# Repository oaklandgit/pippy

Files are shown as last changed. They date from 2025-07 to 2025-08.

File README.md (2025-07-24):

pippy-logo

> [!IMPORTANT] 
> **Pippy is a work in progress, evolving in the open.** Expect bugs, half-built features, and changing plans. \
> [Follow the dev log here](devlog/)

Pippy is a compact, text-first Linux computer with a deliciously tactile 47-key mechanical keyboard. It connects to your iPad with a single USB cable, providing the Pippy with its power and display. Pippy returns the favor with a real shell, focused terminal tools, and a satisfying typing experience. It’s a seamless, symbiotic setup: minimalist, portable, and built for people who love computing at its most intentional.

> [!NOTE]
> The mascot is named "Shelby" or just "Shel" for short. Fun fact: there are _tortoises_ (land) and _turtles_ (water). Shelby is a _tortle_ (air).
> 
85CDC034-619D-4F67-B4E2-E74E878EFC01_1_102_o

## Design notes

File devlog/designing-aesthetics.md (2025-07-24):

CleanShot 2025-07-22 at 15 44 50

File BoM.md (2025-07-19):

# Bill of Materials (BoM)

This file documents all hardware, electronic, and software components used in the **Pippy** project. I'd call it a $150 project, depending on what materials you use for the enclosure.

## Hardware

| Item | Quantity | Purpose | Approx. $ |
| --- | --- | --- |---:|
| [Raspberry Pi Zero W](https://www.raspberrypi.com/products/) | 1 | Main computer | $15.00 |
| MicroSD Card (64GB A1, Class 10) | 1 | Storage and OS — fast, reliable boot performance | $12.00 |
| 4-Port USB Hub (e.g. [Adafruit 4115](https://www.adafruit.com/product/4115))  | 1 | Compact USB expansion hub | $7.00 |
| USB-A to Micro USB Cable (flexible) | 1 | Connects hub to Pi Zero | $9.00 |
| USB-A to USB-C Cable (flexible) | 1 | Connects hub to keyboard | $9.00 |
| 47-key Mechanical Keyboard (e.g. [MicroCenter](https://www.microcenter.com/product/661264/inland-47-keys-hot-swappable-rgb-wired-mechanical-keyboard)) | 1 | Tactile custom keyboard with backlighting | $40.00 |
| Custom Keycaps (e.g. [FKCaps.com](https://fkcaps.com/custom/)) | 47 | Low-profile, shine-through, MX-compatible caps | $60.00 |

iPad not included.

## Software

- iPad Terminal application (e.g. [Termius](https://termius.com/free-ssh-client-for-ipad) or [Le Terminal](https://apps.apple.com/us/app/la-terminal-ssh-client/id1629902861))
- Raspberry Pi OS (Legacy, 32-bit "Bullseye")
- Pippy (see [setup the guide](docs/setup-guide.md))

## Enclosure

- Basswood (for now!)

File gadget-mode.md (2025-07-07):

# Setting up a direct connection between a Pi Zero W and an iPad with "USB Gadget Mode"

July 2-5, 2025 

I've been working on building my dream console I'll refer to as "Pippy." In concept, it's compact, yet sports a delicious-to-type-on ortholinear "planck" style keyboard, and is driven by a Raspberry Pi Zero W under the hood. What it lacks in power it makes up for in portability, user experience, and a chill, retro aesthetic.

From the start, while the choice of keyboard was obvious to me, a suitable display and battery proved elusive. I simply couldn't find a screen with the brightness, power efficiency and form factor I wanted.

But it occured to me that I already have a device with a display and battery that I would want to carry around alongside Pippy anyway. My iPad.

My iPad Air not only has a nice, bright screen and long-lasting battery, its form factor is ideal for drawing and content consumption.

What my iPad sorely lacks, however, is the ability to do any modicum of coding (for my professional work as a user experience designer and software developer) and tinkering with the system itself (part and parcel for what it means to do computing IMHO). Despite all the processing power of its iPad lineup, Apple still refuses to endow it with the capabilities of an openly-accessible system like MacOS. Despite recently-announced updates that give iPadOS a more Mac-like windowing experience, it's not sufficient for coders and tinkerers like myself.

By pairing an iPad with a Raspberry Pi, I could leverage each's strengths: all the benefits of iPad things while providing power and a great display power for my Pi, so that *it* can handle the Linuxy things.

But figuring out precicely *how* sent me down a rabbit hole of false starts, dead ends. And while it was surprisingly tricky to figure out how to actually pull it off, once I learned it is actually quite elegant and easy.

So I'll share that with you. But first, let's look at…

### What Didn't Work

#### Over-the-Network Connectivity
Using SSH and VNC to interact with a Pi over the network is trival, and there are plenty of tutorials to show you the ropes. Basically, both the iPad and Pi join the same network, and the Pi is configured to open its SSH and/or VNC to be accessed by a guest device. It works fine, but has one fatal flaw for my use case: It's not a good choice for use on a *portable, and integrated* device because it relies on that shared network connection which 1) may not always be available and 2) must be configured on each device to join a new network and 3) firewalls and the like. Also, it seems like overkill to leverage a *remote-connection* technology by two devices that are literally attached to one another!

#### Serial UART Connectivity
Which brings me to the option of serial communications. Could I connect from the iPad's USB C to the Pi using good, old-fashioned TX and RX? Between a Mac and Pi yes. You need USB to Serial adapter (ie one with an FTDI chip) and some simple wiring to the Pi's GPIO pins. But when you swap in an iPad for the Mac, you're suddenly faced with the frustrating truth: being a closed system, the only devices and software I could find to make that connection are proprietary and expensive (and often recurring, subscription-based at that!) No thanks. Regardless, even if it were free, Serial has limitations of its own. It's a slow way to send data back and forth. Remember, these 2 devices are meant to act as one. Being *physically connected* yet still slower than Over-the-Network connectivity seemed like a step backwards.

### Enter "USB Gadget Mode!"
This solution not only works for my use case, it brings with it benefits that align perfectly that -- once you figure out *how* -- does not feel at all like a hack. It's both elegant and aligned with the task.

Basically, USB Gadget mode turns a USB connection into a direct ethernet connection between the devices. While ethernet is itself a "networking" technology, it is fast enough to be considered a bridge for local computing. When you keep in mind that a cluster of Raspberry Pis are often wired together via Ethernet as a single big brain, you realize this. And one incredibly convenient benefit is that this connection can share both data and power, which speaks to my original goal: using my iPad as a display AND power source for the Pi.

### Here's how to do it:

(I'm capturing this both for readers who might be interested in using this setup in their projects, but also for future me who -- despite having spent the better portion of a week focused on this -- will certainly forgot how once the dust has settled and I've gone on to the next shiny problem.)

#### STEP 1: Make the physical connection
Connect the Mac or iPad's USB C port to the Pi's Micro USB Data/Power port. IMPORTANT: Make sure to use the Data/Power USB port on the Pi and NOT the Power-only one. Also make sure your cable isn't garbage. **An additional Power source is not required!** The Pi will receive its power from the Gadget Mode connection.

#### STEP 2: Configure the Pi for Gadget Mode
Add the following to the `[all]` section of `/boot/config.txt`

```sh
dtoverlay=dwc2
```

Add `modules-load=dwc2,g_ether` after `rootwait` in `/boot/cmdline.txt`. **Make sure it's all on one line, and notice where there are and aren't spaces.** It doesn't matter if what you have is different as long as `modules-load=dwc2,g_ether` is inserted after `rootwait`.

```sh
console=serial0,115200 console=tty1 root=PARTUUID=71603c9d-02 rootfstype=ext4 fsck.repair=yes rootwait modules-load=dwc2,g_ether quiet splash plymouth.ignore-serial-consoles cfg80211.ieee80211_regdom=US
```

### STEP 3: Configure networking on the Pi 
**Here's the part that I haven't found well documented elsewhere.**

I had two problems at this point. 1) The Pi would not cooperate with dynamic IP addresses and 2) The Pi could only handle one type of connection at a time, which means it couldn't access the Internet while simultaneously connected to the iPad. Sort of a a dealbreaker.

The solution is to set up the Pi with a static IP address for the USB mode, and two interfaces: "usb0" for allowing the iPad to connect to it and "wlan0" for giving itself access to the Interwebs.

To do this, add this to the end of `/etc/dhcpcd.conf`

```sh
interface usb0
    static ip_address=192.168.2.2/24
    static routers=192.168.2.1
    static domain_name_servers=192.168.2.1 8.8.8.8
    metric 300

interface wlan0
    metric 100
```

#### STEP 3A: Connecting from a Mac
Even though a Mac-to-Pi connection was not my intended goal, I found it helpful to do first since there are fewer gotchas.

mac-interface
1. Find the "RNDIS/Ethernet Gadget" interface in `System Preferences → Network`
2. Manually configure IP to `192.168.2.1`, subnet mask to `255.255.255.0`

#### STEP 3B: Connecting from an iPad
1. Since the iPad only has a single USB C port, this is where a small USB hub becomes necessary: Keyboard and Pi Zero → Hub → iPad USB C.
2. You'll find the RNDIS/Ethernet gadget connection under `Settings → Ethernet`. There, they work the same as on a Mac. Set the Manual IP and Subnet Mask.
3. On the iPad, `Accessibility → Keyboards & Typing → Full Keyboard Access` should be turned OFF. With it on, many of the iPad's special keyboard shortcuts for operating the iPad interfere with the SSH Client (Blink app).

#### STEP 4: Give it a whirl!
You should be able to connect the same way you would over the network, using the machine's host name, as opposed to the IP address. Of course, use the username and hostname of your Pi.
```sh
ssh laz@pippy.local
```

### Changing WIFI networks
To recap, the whole point of this was to be able to connect an iPad to a Pi Zero with a single USB cable even without them both being on a shared network. That said, you likely DO want the Pi to have Internet access and, as mentioned, the iPad won't share it's connection because Tim Cook said so. We prepared for this by setting up `wlan0` in step 3, but how do we provide our credentials for new WIFI locations? Pretty simple:

```sh
sudo raspi-config
```
CleanShot 2025-07-05 at 06 12 37

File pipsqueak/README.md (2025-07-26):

PipSqueak is a bespoke game and UI framework for bridging the Pippy with the companion Pippy App for iPad.

It will leverage embedded Lua as a lightweight scripting language driven by a Go runtime. Go will interpret .squeak files and transmit them over the USB Gadget mode (serial) which the iPad app will then render. Inputs and touch events from the iPad will be sent back.

Usage will be like:

```sh
pipsqueak hello.lua
```

which will parse the script and send json across the serial channel.

```json
{"type":"text","data":{"X":20,"Y":30,"Text":"Hello, Pippy!"}}
{"type":"text","data":{"X":30,"Y":40,"Text":"Testing 1, 2, 3."}}
{"type":"rect","data":{"X":10,"Y":50,"W":100,"H":40,"Color":"red"}}
{"type":"rect","data":{"X":10,"Y":1,"W":100,"H":40,"Color":"red"}}
{"type":"rect","data":{"X":10,"Y":2,"W":100,"H":40,"Color":"red"}}
{"type":"rect","data":{"X":10,"Y":3,"W":100,"H":40,"Color":"red"}}
```

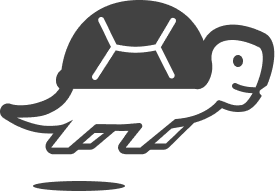
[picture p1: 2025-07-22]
branding/shelby-bw.png

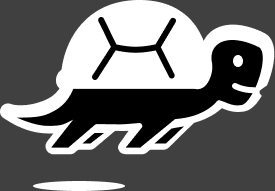
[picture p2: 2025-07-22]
branding/shelby-inverted.png

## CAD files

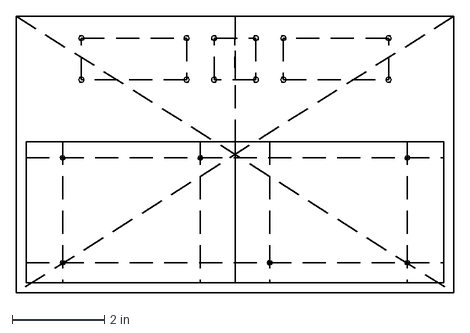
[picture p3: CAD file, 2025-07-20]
enclosure/components-layout.dxf
9.50 x 6.00 in

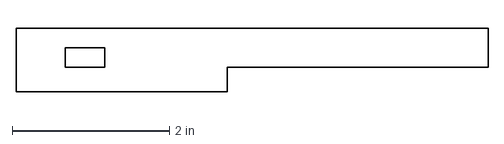
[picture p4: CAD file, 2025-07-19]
enclosure/side.dxf
6.00 x 0.812 in

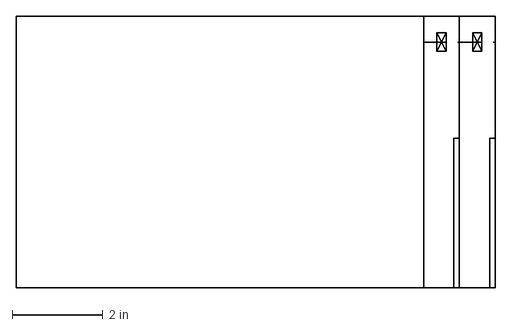
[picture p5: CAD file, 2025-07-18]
enclosure/base-and-sides.dxf
10.6 x 6.00 in

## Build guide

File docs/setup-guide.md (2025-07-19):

# Pippy Setup guide

Follow these steps if you have a Pippy without a pre-flashed SD card.

## Create a Boot SD

On another computer, use Raspberry Pi Imager to prepare a bootable SD card for Pippy:

1. Device: Raspberry Pi Zero W or Raspberry Pi Zero 2 W
2. OS: Raspberry Pi OS (Legacy, 32-bit)

    > The above OS version (aka "Bullseye") is an older version of the OS.
    > Due to differences in how they handle networking, newer versions (ie "Bookworm") do not yet work with Pippy.

4. Storage: 64 GB or above to be comfortable.

Configure in Raspberry Pi Imager (click the gear icon before flashing):

1. Enable SSH
2. Set a username: admin
3. Set a hostname: pippy
4. Set a password: anything you like
5. Configure Wi-Fi: enter your Wi-Fi SSID and password

    > Once Pippy is fully configured, you won’t need Wi-Fi to use it with your iPad — the iPad connects over USB.
    > However, during initial setup, Wi-Fi is required so Pippy can download and install the necessary software.

## Boot Your Pippy

1. Insert the flashed SD card into your Pippy.
2. Connect Pippy to your iPad using a USB-C to USB-C cable. This provides power and display, but network-over-USB will not work until Pippy is fully configured.
3. Wait ~30 seconds. You should see the red power LED light up.

You’ll configure USB networking later during the Pippy software setup process.

## Connect from iPad

1. On your iPad, launch [La Terminal](https://apps.apple.com/us/app/la-terminal-ssh-client/id1629902861), [Termius](https://apps.apple.com/us/app/termius-modern-ssh-client/id549039908), or any app that supports SSH.
2. After the Pi boots, connect via:

```
ssh admin@pippy.local
```

3. Enter the password you created earlier when prompted.

#### If pippy.local doesn’t work, check that:

- The Pippy is fully booted
- The USB cable supports data
- Your terminal app has permission to access the network

# Install the Pippy Software

#### Once connected via SSH, run:

```
git clone https://github.com/oaklandgit/pippy.git
cd pippy/scripts
sudo ./setup.sh
```

This script will install everything Pippy needs. You can review or run individual steps from inside the `pippy/setup/` folder if needed.

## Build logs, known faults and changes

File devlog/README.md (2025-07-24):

# Dev Log

[July 2-5, 2025 - Setting up a direct connection between the Pippy and iPad](gadget-mode.md)

[July 6-8, 2025 - Designing the Pippy's Keyboard](keyboard-notes.md)

[July 9, 2025 - Choosing an iPad Terminal App](ipad-terminal-app.md)

[July 21, 2025 - Designing the Aesthetics](aesthetics.md)

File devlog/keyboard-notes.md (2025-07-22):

# Designing the Pippy's Keyboard

305FA7C0-1CFB-466D-AB91-7F12BD7318A7_1_105_c

From the start, the Pippy was meant to be highly portable. But the one thing I would not compromise on is the keyboard.

The biggest downside to comparable devices (Clockwork's [uConsole](https://www.clockworkpi.com/home-uconsole) and [DevTerm](https://www.clockworkpi.com/home-uconsole), are that the keyboards are more geared to thumb typing than traditional touch typing.

I want to type on something that feels, for lack of a better word, _delicious._

The challenge here is to combine a delicious typing experience with a small form factor. So I gave [planck-style keyboards](https://youtu.be/bEPg8kk84gw) a try.

These keyboards have only 47 keys (12 wide, 4 tall, and the space key takes up 2 spaces == 47)

I found a good model (Inland MK-47 from Micro Center) that I could incorporate into my design and I used the great web-based tool [via](https://via.evove.top/) to flash the layout. (Planck keyboards use the concept of "layers" for creating different modes so that one can cram all the necessary keyboard functionality into fewer keys.)

And finally, I'm in the process of making custom keycaps that make it clear to the user how to access that functionality.

CleanShot 2025-07-08 at 11 25 36

You can even order this keycap set yourself at:
[My keycaps design at Yuzu.](https://yuzukeycaps.com/c/9839bc54-8ba7-46e9-92d4-aec02bd5d362)

UPDATE:

The Inland MK-47 Planck keyboard comes with RGB backlighting and effects. That "gamer" vibe isn't exactly the aesthetic I'm after, but I did want to take advantage of it as a keyboard backlight. And I added legends for the backlight brightness (and volume while I was at it) to the firmware (via Via 😉) and the YUZU keycaps.

However, after I ordered the keycaps, two things occurred to me. For backlighting to work the key caps need to be: 1) shine through and 2) not white! (I have a Logitech MX keyboard with white shine-through caps. The white caps make it impossible to even see the legends when the backlight is on which, needless to say, defeats the purpose! I, however, strive to be more thoughtful in my design!)

So I did some more searching and found [FK Keycaps](https://fkcaps.com/) who has low profile keycaps with shinethrough and standard MX stems to fit my existing switches. Just the trick!

CleanShot 2025-07-09 at 11 08 50

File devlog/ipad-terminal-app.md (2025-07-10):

# Finding the right iPad terminal app for interfacing with the Pi

First tried Termius, which worked ok until I decided I wanted the Pippy ecosystem to support images in the terminal. There's something called the Terminal Image Protocol that allows this, but it must be supported by the terminal. Despite various claims of support, I've only ever had luck in certain MacOS terminals (Kitty, the creator of the protocol, and iTerm2) but not Termius on the iPad.

Luckily, I found a single search result on Y Combinator mentioning this gem: [La Terminal](https://apps.apple.com/us/app/la-terminal-ssh-client/id1629902861), which not only supports the image protocol, but is overall better-implemented than Termius IMO. (One example being more customization options).

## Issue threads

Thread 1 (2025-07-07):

Try installing dnsmasq for dynamically handing out IP addresses to connected iPad.

oaklandgit, 2025-07-07:
Problem
======
Current implementation requires end user to change USB Gadget interface to static IP.

Possible Solution
=============
Try configuring pi with dnsmasq to hand out dynamic IPs on the usb0 interface.

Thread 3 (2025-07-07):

Order custom keycaps based on attached VIA layout

oaklandgit, 2025-07-07:
[mk47.layout.json](https://github.com/user-attachments/files/21097711/mk47.layout.json)

oaklandgit, 2025-07-07:
https://yuzukeycaps.com/playground

oaklandgit, 2025-07-07:
Proposed layout:

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

oaklandgit, 2025-07-08:
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

oaklandgit, 2025-07-12:
Ordered. But also ordered shine-thru low profile black caps from fk keycaps. [Read about it here](https://github.com/oaklandgit/pippy)

Closed 2025-07-12.

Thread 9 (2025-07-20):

Wire up a simple PWM speaker

oaklandgit, 2025-07-20:
to play music via Python et al

oaklandgit, 2025-07-24:
Using PipSqueak, we'll be able to send audio through the companion app (I hope). This piezo speaker will still be useful for indicating things on the Pippy even before the connection to the companion app is established.

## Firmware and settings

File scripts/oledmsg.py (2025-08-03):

#!/usr/bin/env python3

import sys
import time
import os
import Adafruit_SSD1306
from PIL import Image, ImageDraw, ImageFont

font_size = 16 
line_height = 16
font_path = os.path.expanduser("~/pippy/assets/3270NerdFontMono-Regular.ttf")
font = ImageFont.truetype(font_path, font_size)

# --- Argument Parsing ---
args = sys.argv[1:]
duration = None
lines = []

i = 0
while i < len(args):
    if args[i] in ("-d", "--duration"):
        i += 1
        if i < len(args):
            try:
                duration = float(args[i])
            except ValueError:
                print("Invalid duration:", args[i])
                sys.exit(1)
        else:
            print("Missing value for -d")
            sys.exit(1)
    else:
        lines.append(args[i])
    i += 1

# If input is piped, override with stdin
if not sys.stdin.isatty():
    lines = [line.strip() for line in sys.stdin if line.strip()]

# --- OLED Setup ---
disp = Adafruit_SSD1306.SSD1306_128_32(rst=None)
disp.begin()
disp.clear()
disp.display()

width, height = disp.width, disp.height

image = Image.new('1', (width, height))
draw = ImageDraw.Draw(image)
#line_height = font_size 
max_lines = height // line_height
lines = lines[:max_lines]

# --- Drawing ---
draw.rectangle((0, 0, width, height), fill=0)
for i, line in enumerate(lines):
    y = i * line_height
    draw.text((0, y), line, font=font, fill=255)

disp.image(image)
disp.display()

# --- Duration ---
if duration is not None:
    time.sleep(duration)
    disp.clear()
    disp.display()

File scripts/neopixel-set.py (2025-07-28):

#!/usr/bin/env python3

# NOTE: Must be run as root
import board
import neopixel
import sys

NUM_PIXELS = 8 # number of pixels
pixels = neopixel.NeoPixel(board.D18, NUM_PIXELS, brightness=0.5, auto_write=False)

# if 3 args, set all pixels
if len(sys.argv) == 4:
    r, g, b = map(int, sys.argv[1:4])
    for i in range(NUM_PIXELS):
        pixels[i] = (r, g, b)

# if 4 args, set a single pixel
elif len(sys.argv) == 5:
    idx = int(sys.argv[1])
    r, g, b = map(int, sys.argv[2:5])
    if 0 <= idx < NUM_PIXELS:
        pixels[idx] = (r, g, b)
    else:
        print(f"Pixel index must be 0-{NUM_PIXELS - 1}")
        sys.exit(1)
else:
    print("Usage:")
    print("  neopixel-set.py R G B        # set all")
    print("  neopixel-set.py IDX R G B    # set one")
    sys.exit(1)

pixels.show()

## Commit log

2025-07-04 Add note about battery pack.
2025-07-05 Discuss connecting to new WIFI networks
    …via raspi-config
2025-07-10 Fix bill of materials.
2025-07-10 Further clean up BoM.
2025-07-11 1) Update devlog to mention that my usb gadget mode instructions are only for 'bullseye' OS. 2) Set execute flag on scripts. 3) Update scripts back to /boot/config.txt and /boot/cmdline.txt. The firm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
2025-07-18 Hardware schematics and blender mocks. (Works in progress).
    [acrylic_enclosure.blend, base-and-sides.dxf]
2025-07-19 Some OLED stuff.
    [SIDE.dxf]
2025-07-20 Add branding assets. Move example script.
    [BOTTOM SKETCH.dxf]
2025-07-22 File organization. Add VIA keyboard layout json to project.
    [base-and-sides.dxf, components-layout.dxf, side.dxf]
2025-07-22 Remove unimportant directory.
    [acrylic_enclosure.blend]
2025-07-24 Add assets folder with powerline font.
2025-07-26 Create script for installing dtoverlay for pwm (pulse width modulation) that neopixels will require.
